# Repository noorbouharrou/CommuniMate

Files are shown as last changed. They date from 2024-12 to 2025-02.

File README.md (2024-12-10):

# CommuniMate

## Getting started

To make it easy for you to get started with GitLab, here's a list of recommended next steps.

Already a pro? Just edit this README.md and make it your own. Want to make it easy? [Use the template at the bottom](#editing-this-readme)!

## Add your files

- [ ] [Create](https://docs.gitlab.com/ee/user/project/repository/web_editor.html#create-a-file) or [upload](https://docs.gitlab.com/ee/user/project/repository/web_editor.html#upload-a-file) files
- [ ] [Add files using the command line](https://docs.gitlab.com/ee/gitlab-basics/add-file.html#add-a-file-using-the-command-line) or push an existing Git repository with the following command:

```
cd existing_repo
git remote add origin https://gitlab.cmi.hro.nl/1048112/communimate.git
git branch -M main
git push -uf origin main
```

## Integrate with your tools

- [ ] [Set up project integrations](https://gitlab.cmi.hro.nl/1048112/communimate/-/settings/integrations)

## Collaborate with your team

- [ ] [Invite team members and collaborators](https://docs.gitlab.com/ee/user/project/members/)
- [ ] [Create a new merge request](https://docs.gitlab.com/ee/user/project/merge_requests/creating_merge_requests.html)
- [ ] [Automatically close issues from merge requests](https://docs.gitlab.com/ee/user/project/issues/managing_issues.html#closing-issues-automatically)
- [ ] [Enable merge request approvals](https://docs.gitlab.com/ee/user/project/merge_requests/approvals/)
- [ ] [Set auto-merge](https://docs.gitlab.com/ee/user/project/merge_requests/merge_when_pipeline_succeeds.html)

## Test and Deploy

Use the built-in continuous integration in GitLab.

- [ ] [Get started with GitLab CI/CD](https://docs.gitlab.com/ee/ci/quick_start/index.html)
- [ ] [Analyze your code for known vulnerabilities with Static Application Security Testing (SAST)](https://docs.gitlab.com/ee/user/application_security/sast/)
- [ ] [Deploy to Kubernetes, Amazon EC2, or Amazon ECS using Auto Deploy](https://docs.gitlab.com/ee/topics/autodevops/requirements.html)
- [ ] [Use pull-based deployments for improved Kubernetes management](https://docs.gitlab.com/ee/user/clusters/agent/)
- [ ] [Set up protected environments](https://docs.gitlab.com/ee/ci/environments/protected_environments.html)

***

# Editing this README

When you're ready to make this README your own, just edit this file and use the handy template below (or feel free to structure it however you want - this is just a starting point!). Thanks to [makeareadme.com](https://www.makeareadme.com/) for this template.

## Suggestions for a good README

Every project is different, so consider which of these sections apply to yours. The sections used in the template are suggestions for most open source projects. Also keep in mind that while a README can be too long and detailed, too long is better than too short. If you think your README is too long, consider utilizing another form of documentation rather than cutting out information.

## Name
Choose a self-explaining name for your project.

## Description
Let people know what your project can do specifically. Provide context and add a link to any reference visitors might be unfamiliar with. A list of Features or a Background subsection can also be added here. If there are alternatives to your project, this is a good place to list differentiating factors.

## Badges
On some READMEs, you may see small images that convey metadata, such as whether or not all the tests are passing for the project. You can use Shields to add some to your README. Many services also have instructions for adding a badge.

## Visuals
Depending on what you are making, it can be a good idea to include screenshots or even a video (you'll frequently see GIFs rather than actual videos). Tools like ttygif can help, but check out Asciinema for a more sophisticated method.

## Installation
Within a particular ecosystem, there may be a common way of installing things, such as using Yarn, NuGet, or Homebrew. However, consider the possibility that whoever is reading your README is a novice and would like more guidance. Listing specific steps helps remove ambiguity and gets people to using your project as quickly as possible. If it only runs in a specific context like a particular programming language version or operating system or has dependencies that have to be installed manually, also add a Requirements subsection.

## Usage
Use examples liberally, and show the expected output if you can. It's helpful to have inline the smallest example of usage that you can demonstrate, while providing links to more sophisticated examples if they are too long to reasonably include in the README.

## Support
Tell people where they can go to for help. It can be any combination of an issue tracker, a chat room, an email address, etc.

## Roadmap
If you have ideas for releases in the future, it is a good idea to list them in the README.

## Contributing
State if you are open to contributions and what your requirements are for accepting them.

For people who want to make changes to your project, it's helpful to have some documentation on how to get started. Perhaps there is a script that they should run or some environment variables that they need to set. Make these steps explicit. These instructions could also be useful to your future self.

You can also document commands to lint the code or run tests. These steps help to ensure high code quality and reduce the likelihood that the changes inadvertently break something. Having instructions for running tests is especially helpful if it requires external setup, such as starting a Selenium server for testing in a browser.

## Authors and acknowledgment
Show your appreciation to those who have contributed to the project.

## License
For open source projects, say how it is licensed.

## Project status
If you have run out of energy or time for your project, put a note at the top of the README saying that development has slowed down or stopped completely. Someone may choose to fork your project or volunteer to step in as a maintainer or owner, allowing your project to keep going. You can also make an explicit request for maintainers.

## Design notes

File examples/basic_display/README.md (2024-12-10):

Put the User_Setup.h in the Documents > Arduino > libraries > TFT_eSPI
Library: https://github.com/Bodmer/TFT_eSPI/tree/master

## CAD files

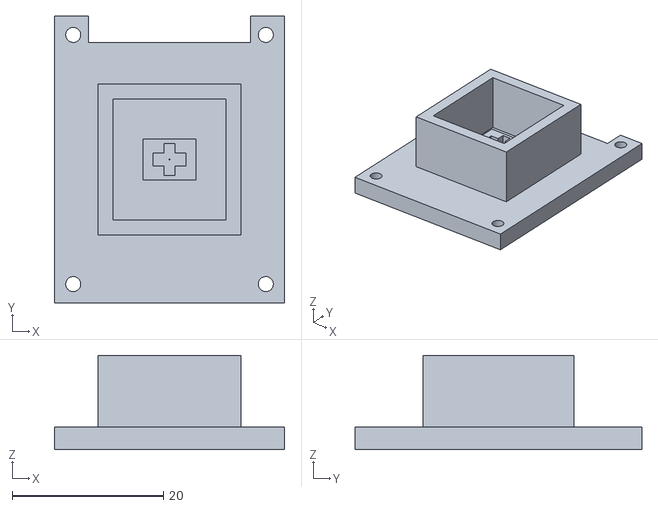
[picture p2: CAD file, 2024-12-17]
ontwerpen/keycap-adapter/key_adapter_V1.stl
30.5 x 38.0 x 12.5

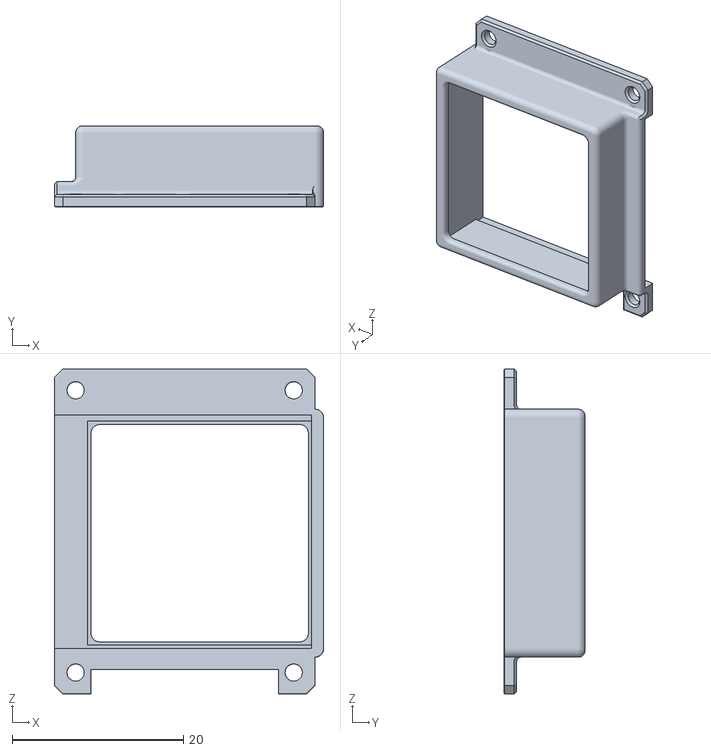
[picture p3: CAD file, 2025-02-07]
ontwerpen/keycap-adapter/STL's/Toets_topshell.STL
31.5 x 9.50 x 38.0

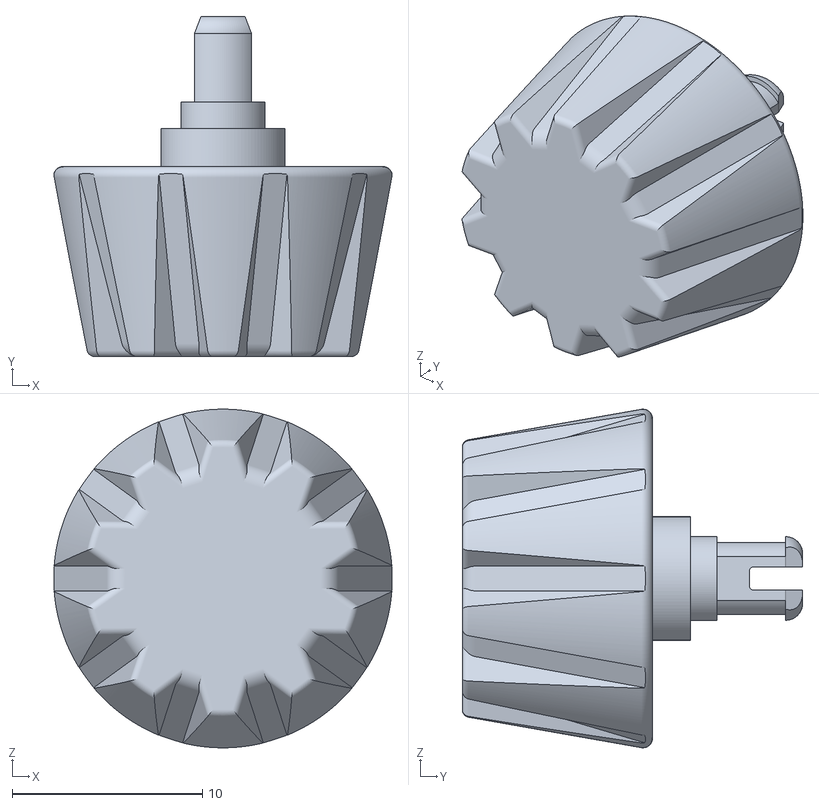
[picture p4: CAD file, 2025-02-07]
ontwerpen/keycap-adapter/STL's/Draaiknop_volume.STL
17.8 x 17.9 x 17.8

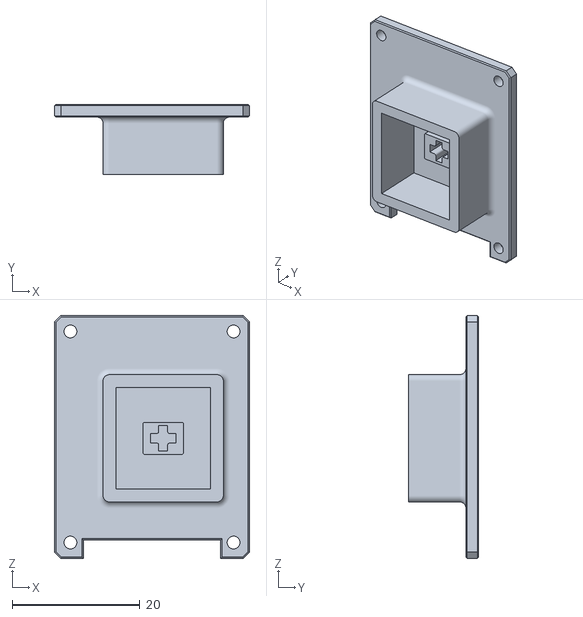
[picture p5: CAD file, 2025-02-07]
ontwerpen/keycap-adapter/STL's/Toets_bottomshell.STL
30.5 x 11.0 x 38.0

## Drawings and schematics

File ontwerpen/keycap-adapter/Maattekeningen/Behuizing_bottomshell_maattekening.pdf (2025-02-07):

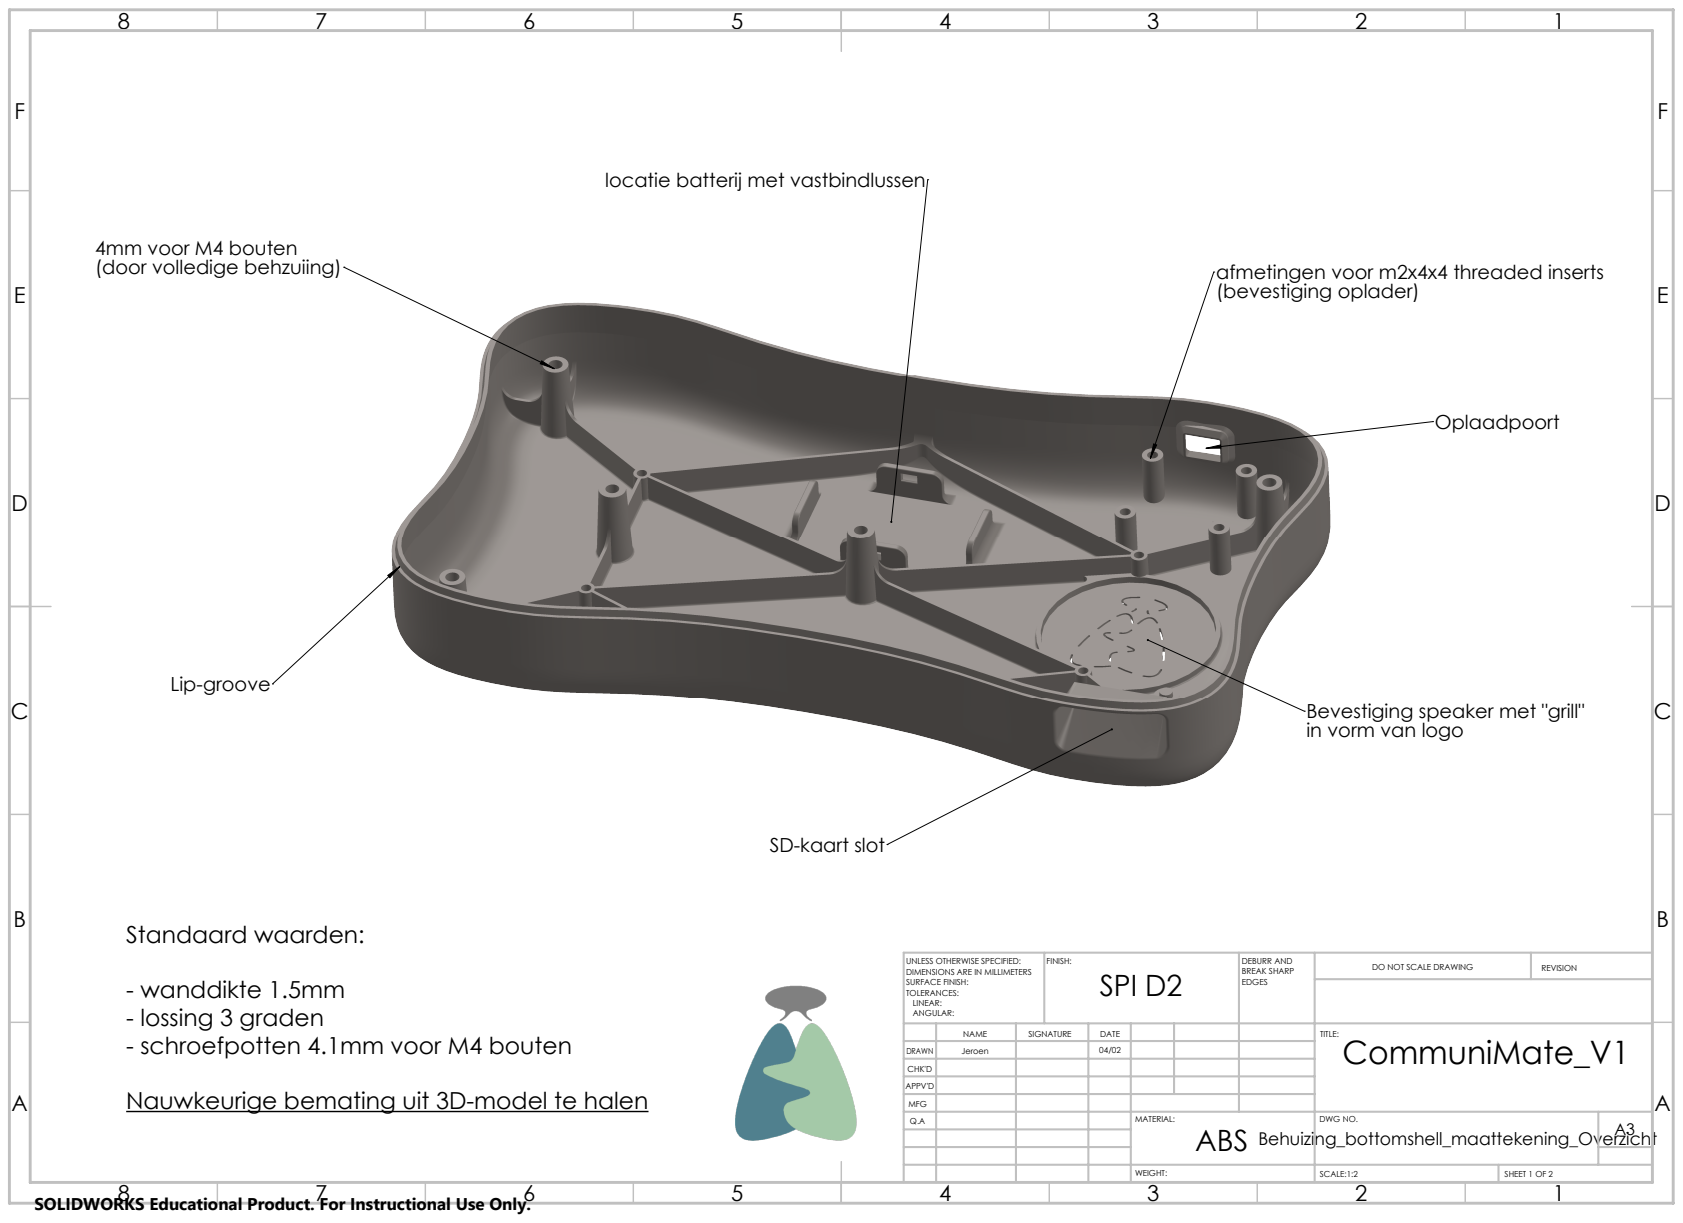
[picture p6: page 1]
4mm voor M4 bouten; (door volledige behzuiing); afmetingen voor m2x4x4 threaded inserts; (bevestiging oplader); Nauwkeurige bemating uit 3D-model te halen; FINISH:; DEBURR AND; BREAK SHARP; DO NOT SCALE DRAWING; REVISION; SCALE:1:2; SHEET 1 OF 2; SPI D2

locatie batterij met vastbindlussen

Bevestiging speaker met "grill"
in vorm van logo

SD-kaart slot

Standaard waarden:
- wanddikte 1.5mm
- lossing 3 graden
- schroefpotten 4.1mm voor M4 bouten

UNLESS OTHERWISE SPECIFIED:
DIMENSIONS ARE IN MILLIMETERS
SURFACE FINISH:
TOLERANCES:
LINEAR:
ANGULAR:

NAME | SIGNATURE | DATE | | | | TITLE: CommuniMate_V1

DRAWN | Jeroen | | 04/02
CHK'D
APPV'D
MFG
Q.A | | | | MATERIAL: ABS Behuizing_bottomshell_maattekening_Overzicht | DWG NO. | A3

SOLIDWORKS Educational Product. For Instructional Use Only.

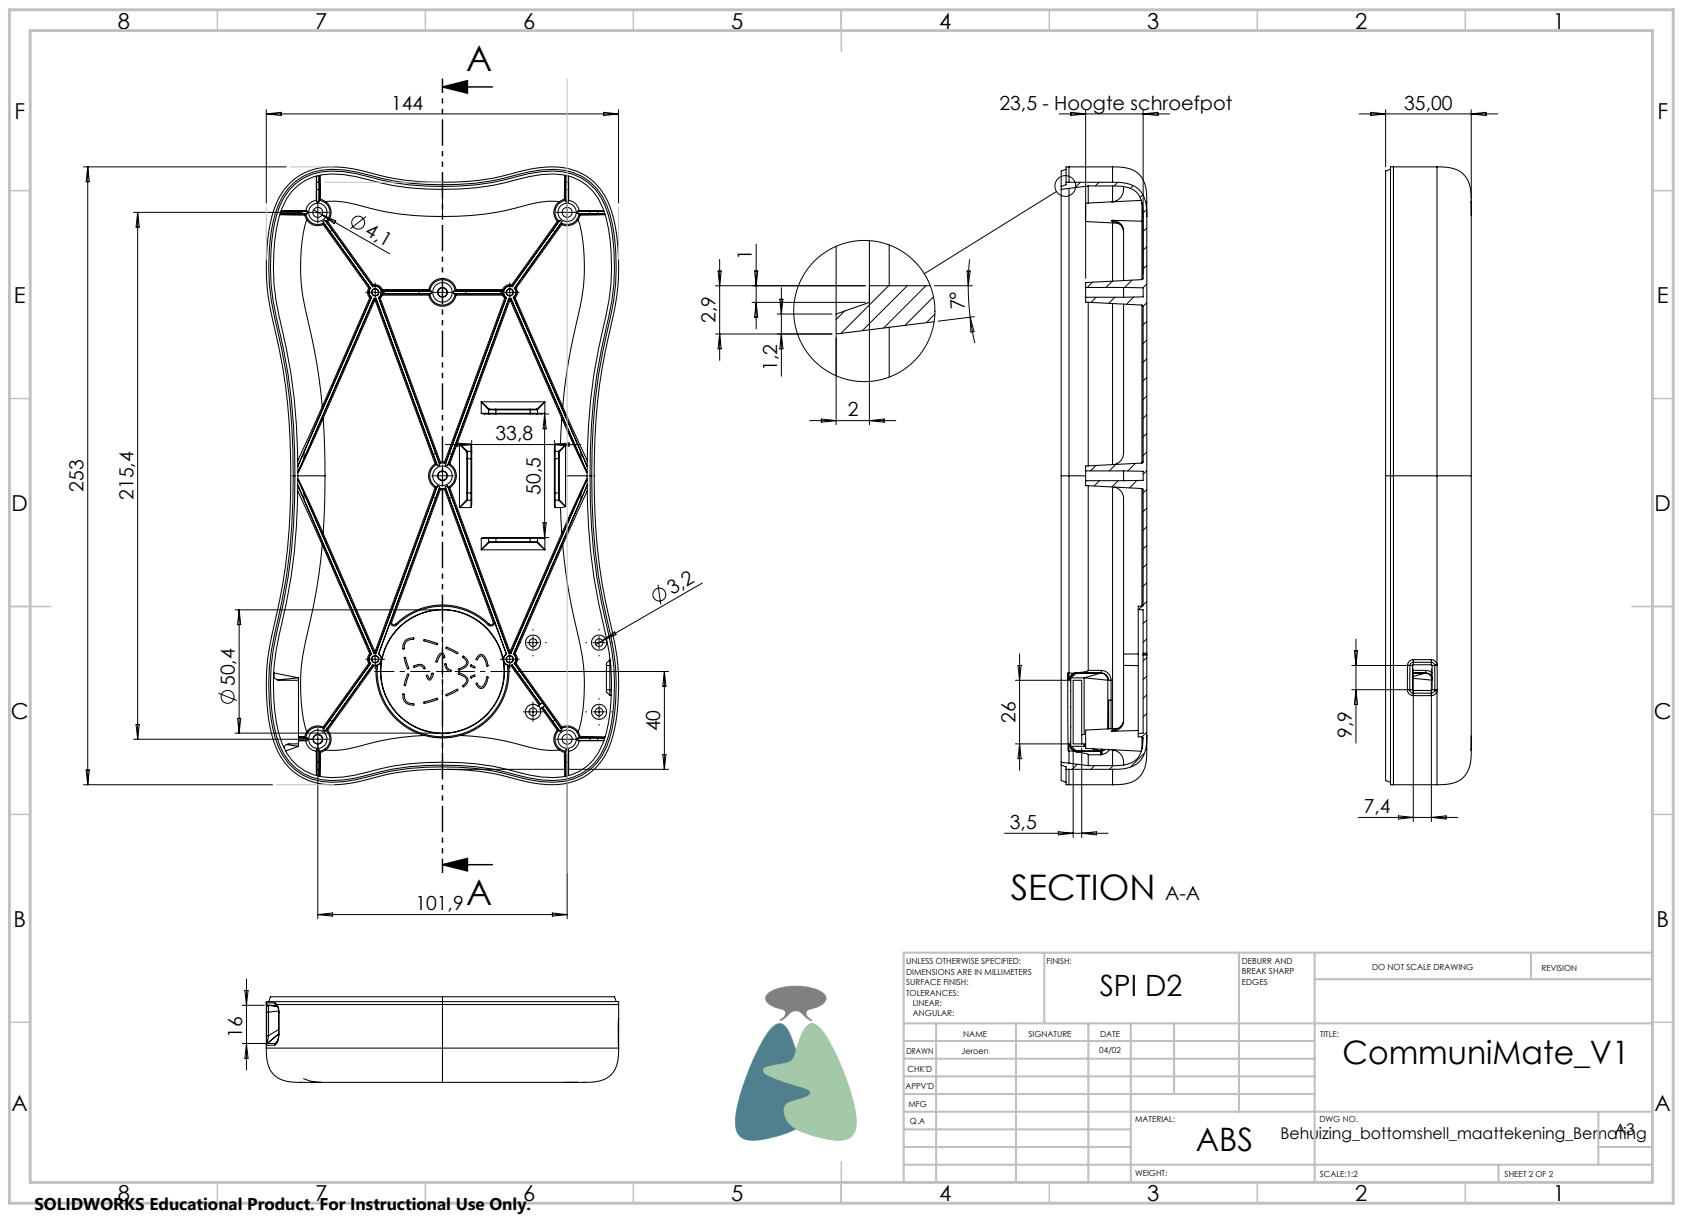
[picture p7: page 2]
23,5 - Hoogte schroefpot; SECTION A-A; FINISH:; DEBURR AND; BREAK SHARP; DO NOT SCALE DRAWING; REVISION; SCALE:1:2; SHEET 2 OF 2; SPI D2

UNLESS OTHERWISE SPECIFIED:
DIMENSIONS ARE IN MILLIMETERS
SURFACE FINISH:
TOLERANCES:
LINEAR:
ANGULAR:

NAME | SIGNATURE | DATE | | | | TITLE: CommuniMate_V1

DRAWN | Jeroen | | 04/02
CHK'D
APPV'D
MFG
Q.A | | | | MATERIAL: ABS Behuizing_bottomshell_maattekening_Bemating | DWG NO. | A3

SOLIDWORKS Educational Product. For Instructional Use Only.

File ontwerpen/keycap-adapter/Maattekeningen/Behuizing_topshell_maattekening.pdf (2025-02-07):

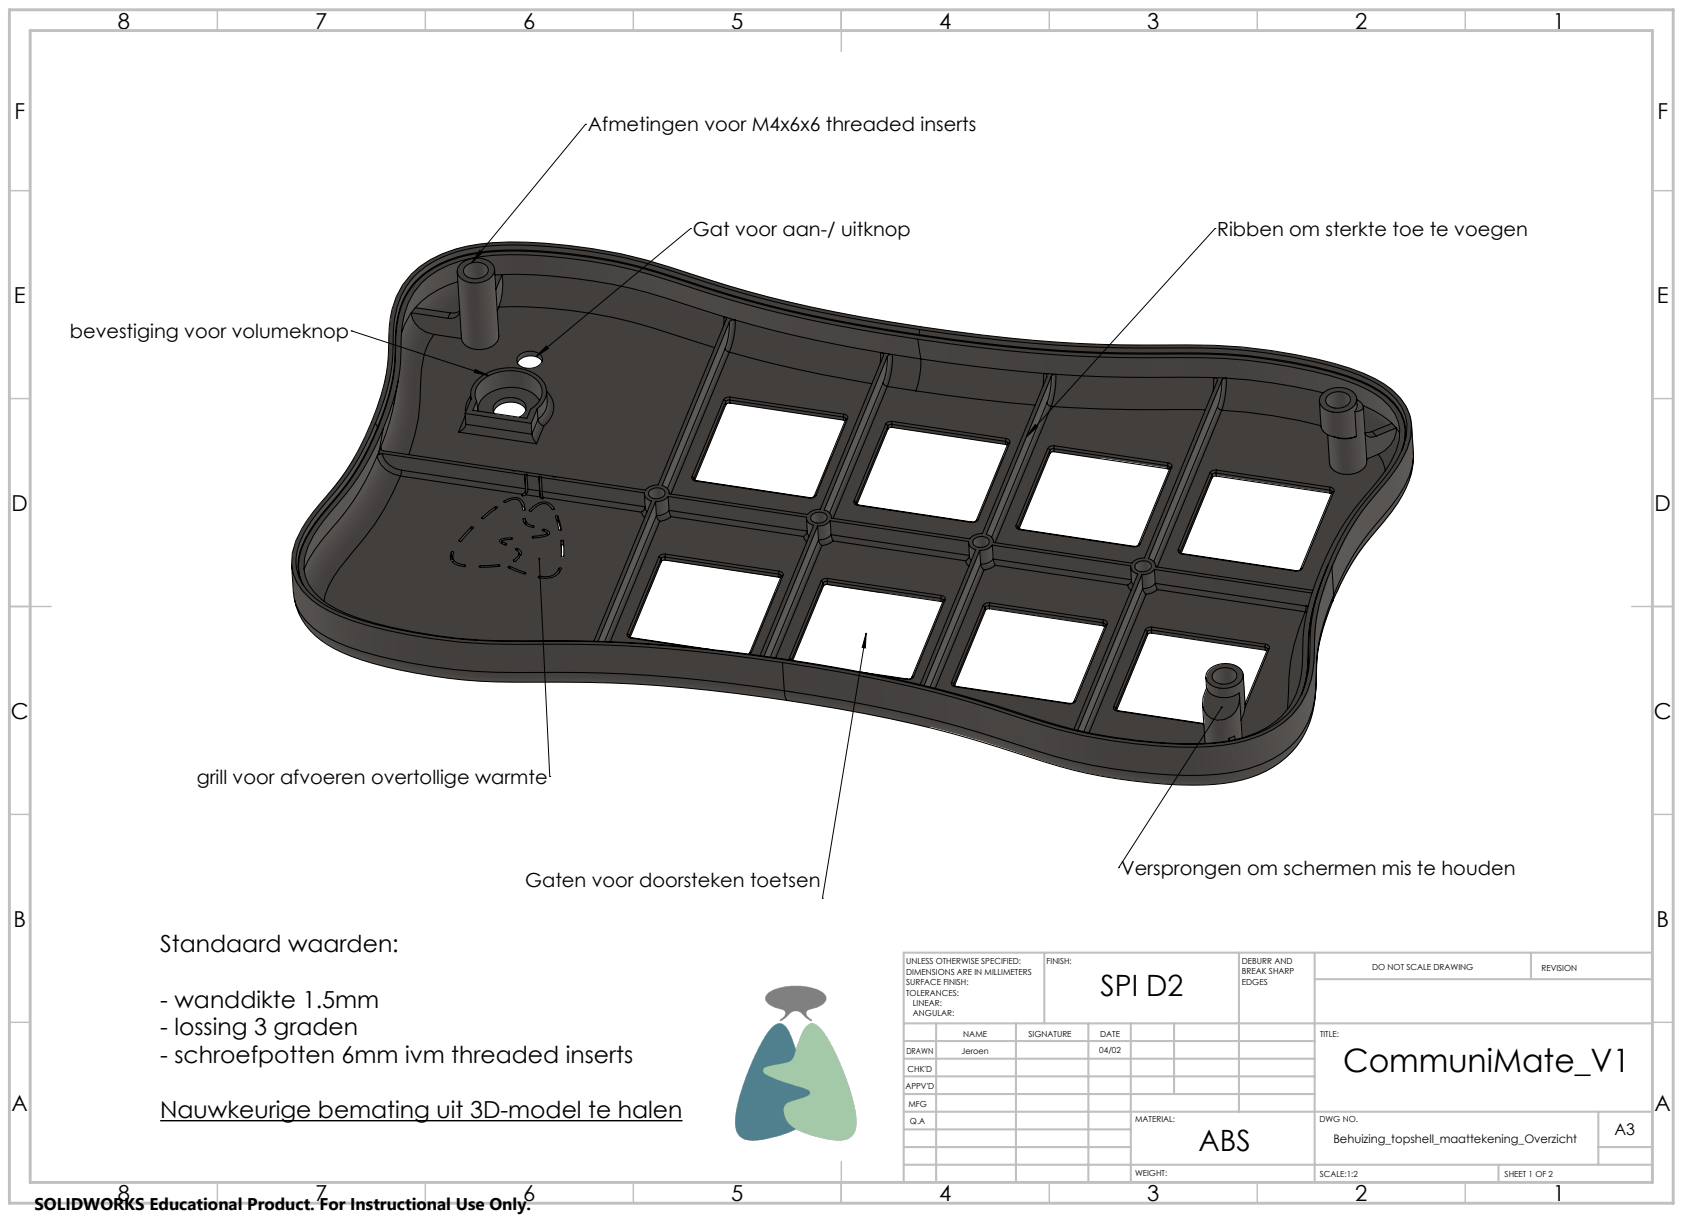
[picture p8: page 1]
Nauwkeurige bemating uit 3D-model te halen; FINISH:; DEBURR AND; BREAK SHARP; DO NOT SCALE DRAWING; REVISION; SCALE:1:2; SHEET 1 OF 2; SPI D2

Afmetingen voor M4x6x6 threaded inserts

Gat voor aan-/ uitknop

Ribben om sterkte toe te voegen

bevestiging voor volumeknop

grill voor afvoeren overtollige warmte

Versprongen om schermen mis te houden

Gaten voor doorsteken toetsen

Standaard waarden:
- wanddikte 1.5mm
- lossing 3 graden
- schroefpotten 6mm ivm threaded inserts

UNLESS OTHERWISE SPECIFIED:
DIMENSIONS ARE IN MILLIMETERS
SURFACE FINISH:
TOLERANCES:
LINEAR:
ANGULAR:

NAME | SIGNATURE | DATE | | | | TITLE: CommuniMate_V1

DRAWN | Jeroen | | 04/02
CHK'D
APPV'D
MFG
Q.A | | | | MATERIAL: ABS | DWG NO. Behuizing_topshell_maattekening_Overzicht | A3

SOLIDWORKS Educational Product. For Instructional Use Only.

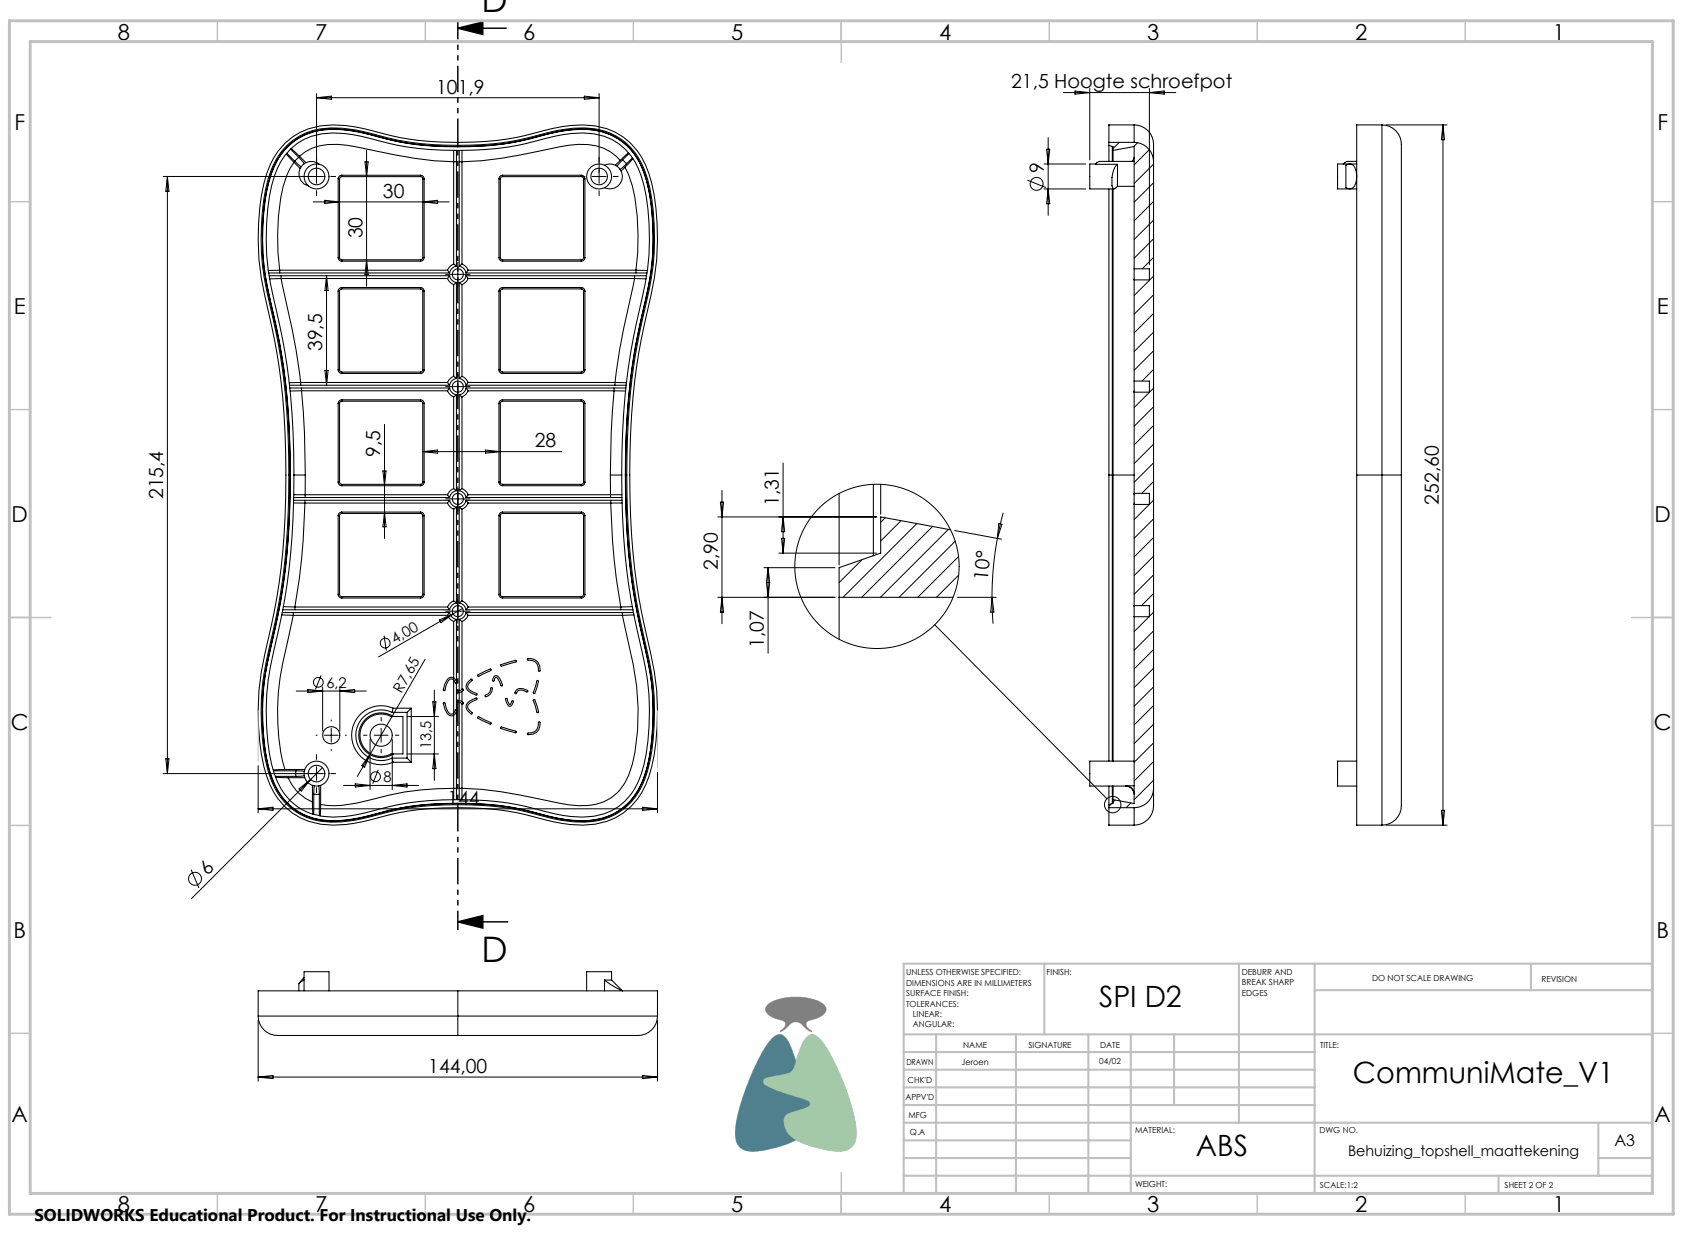
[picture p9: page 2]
21,5 Hoogte schroefpot 9; FINISH:; DEBURR AND; BREAK SHARP; DO NOT SCALE DRAWING; REVISION; SCALE:1:2; SHEET 2 OF 2; SPI D2

UNLESS OTHERWISE SPECIFIED:
DIMENSIONS ARE IN MILLIMETERS
SURFACE FINISH:
TOLERANCES:
LINEAR:
ANGULAR:

NAME | SIGNATURE | DATE | | | | TITLE: CommuniMate_V1

DRAWN | Jeroen | | 04/02
CHK'D
APPV'D
MFG
Q.A | | | | MATERIAL: ABS | DWG NO. Behuizing_topshell_maattekening | A3

SOLIDWORKS Educational Product. For Instructional Use Only.

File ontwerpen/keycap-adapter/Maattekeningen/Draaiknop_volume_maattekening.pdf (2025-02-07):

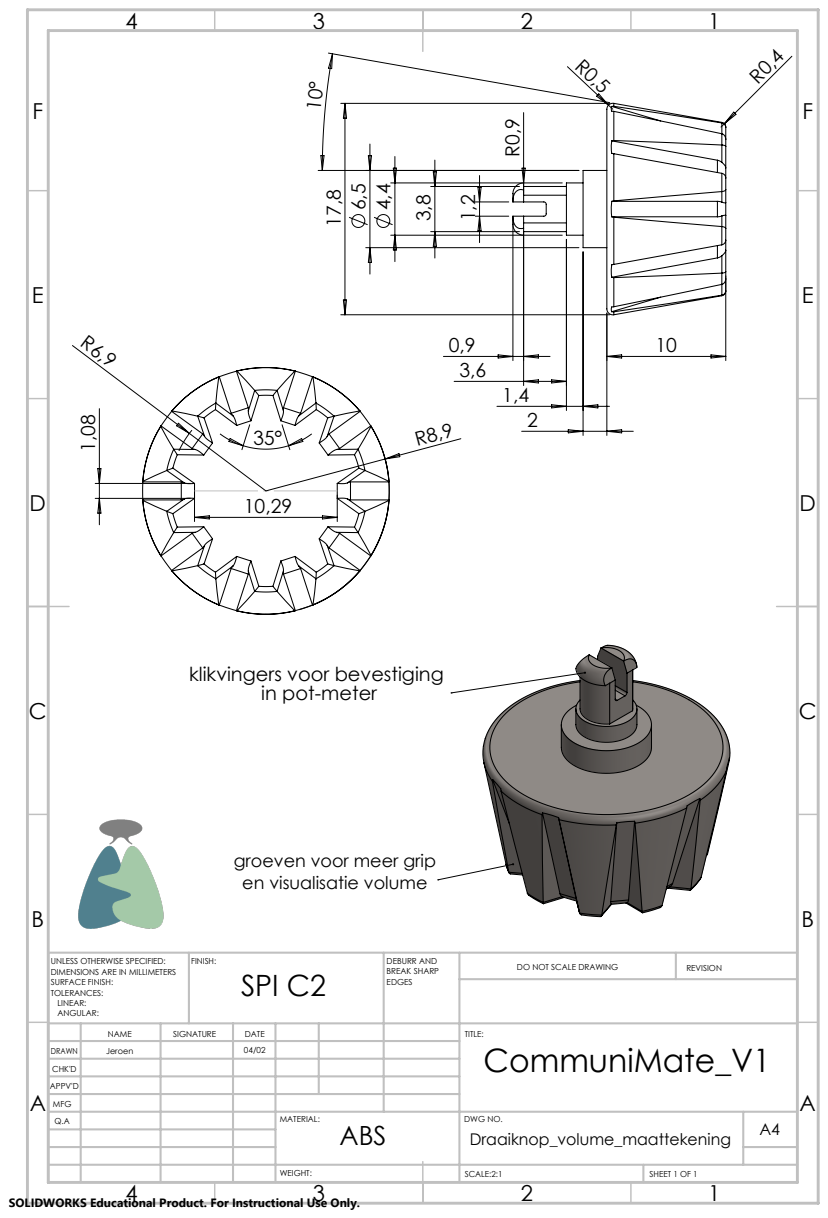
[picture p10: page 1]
en visualisatie volume 4,4; FINISH:; DEBURR AND; BREAK SHARP; DO NOT SCALE DRAWING; REVISION; SCALE:2:1; SHEET 1 OF 1; SPI C2

klikvingers voor bevestiging
in pot-meter

groeven voor meer grip

UNLESS OTHERWISE SPECIFIED:
DIMENSIONS ARE IN MILLIMETERS
SURFACE FINISH:
TOLERANCES:
LINEAR:
ANGULAR:

NAME | SIGNATURE | DATE | | | | TITLE: CommuniMate_V1

DRAWN | Jeroen | | 04/02
CHK'D
APPV'D
MFG
Q.A | | | | MATERIAL: | DWG NO. Draaiknop_volume_maattekening | A4 ABS

SOLIDWORKS Educational Product. For Instructional Use Only.

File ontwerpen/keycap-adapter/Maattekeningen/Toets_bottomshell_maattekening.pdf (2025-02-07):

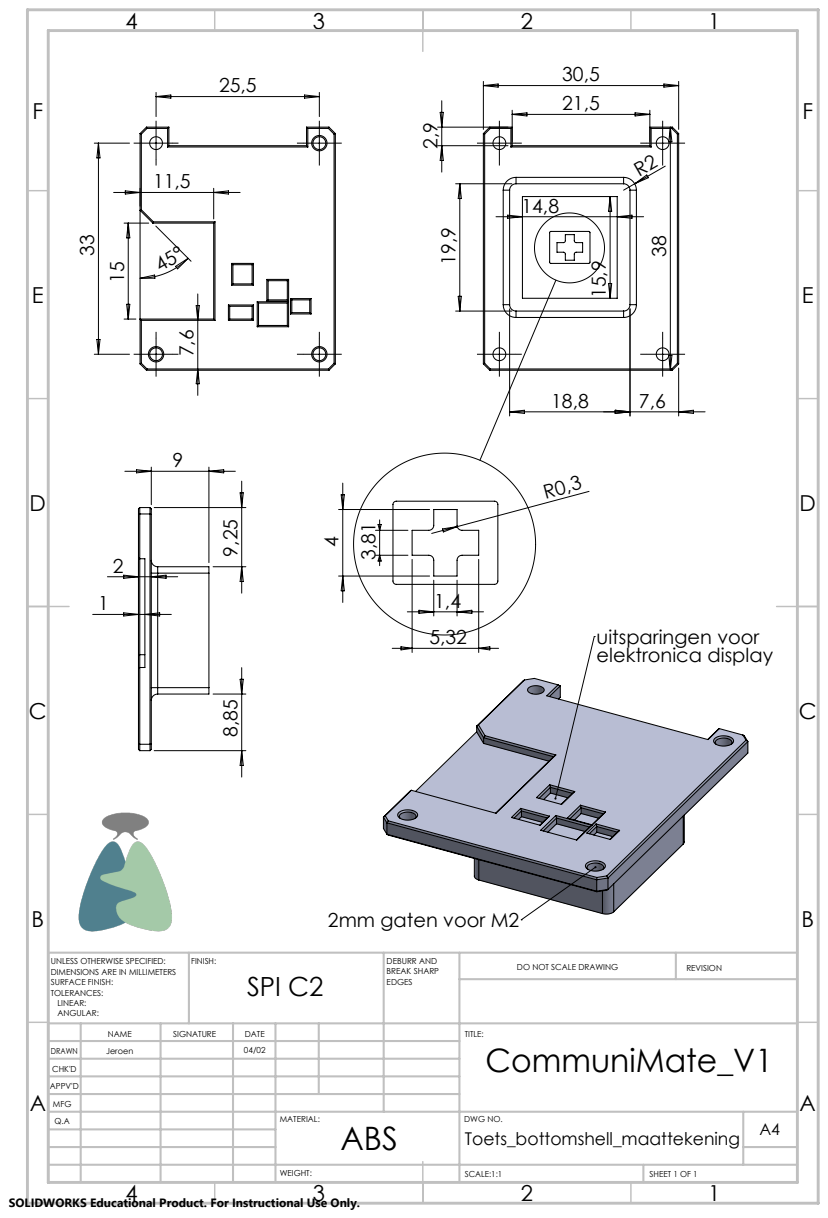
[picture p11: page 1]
uitsparingen voor elektronica display; 2mm gaten voor M2; FINISH:; DEBURR AND; BREAK SHARP; DO NOT SCALE DRAWING; REVISION; SCALE:1:1; SHEET 1 OF 1; SPI C2

UNLESS OTHERWISE SPECIFIED:
DIMENSIONS ARE IN MILLIMETERS
SURFACE FINISH:
TOLERANCES:
LINEAR:
ANGULAR:

NAME | SIGNATURE | DATE | | | | TITLE: CommuniMate_V1

DRAWN | Jeroen | | 04/02
CHK'D
APPV'D
MFG
Q.A | | | | MATERIAL: | DWG NO. Toets_bottomshell_maattekening | A4 ABS

SOLIDWORKS Educational Product. For Instructional Use Only.

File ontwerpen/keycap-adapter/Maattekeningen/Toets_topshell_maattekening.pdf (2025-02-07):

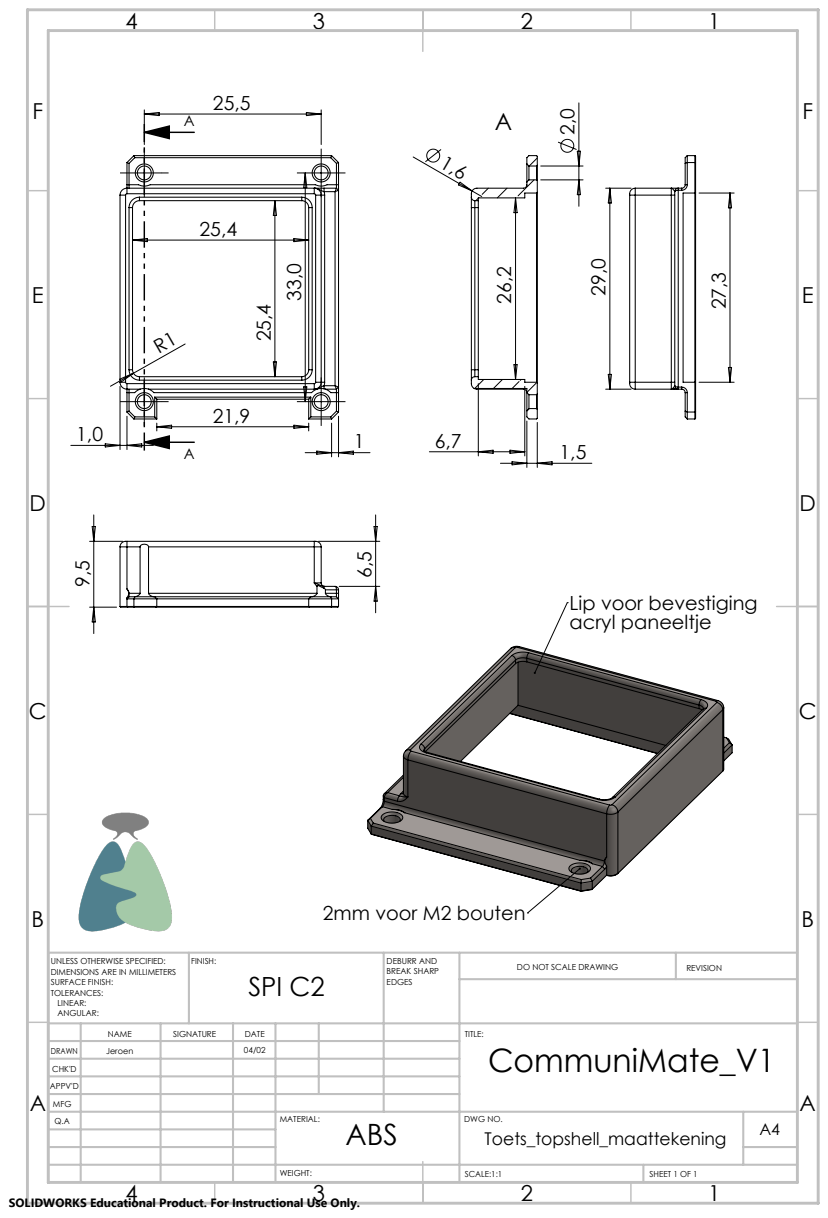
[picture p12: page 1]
2mm voor M2 bouten; FINISH:; DEBURR AND; BREAK SHARP; DO NOT SCALE DRAWING; REVISION; SCALE:1:1; SHEET 1 OF 1; SPI C2

Lip voor bevestiging
acryl paneeltje

UNLESS OTHERWISE SPECIFIED:
DIMENSIONS ARE IN MILLIMETERS
SURFACE FINISH:
TOLERANCES:
LINEAR:
ANGULAR:

NAME | SIGNATURE | DATE | | | | TITLE: CommuniMate_V1

DRAWN | Jeroen | | 04/02
CHK'D
APPV'D
MFG
Q.A | | | | MATERIAL: ABS | DWG NO. Toets_topshell_maattekening | A4

SOLIDWORKS Educational Product. For Instructional Use Only.

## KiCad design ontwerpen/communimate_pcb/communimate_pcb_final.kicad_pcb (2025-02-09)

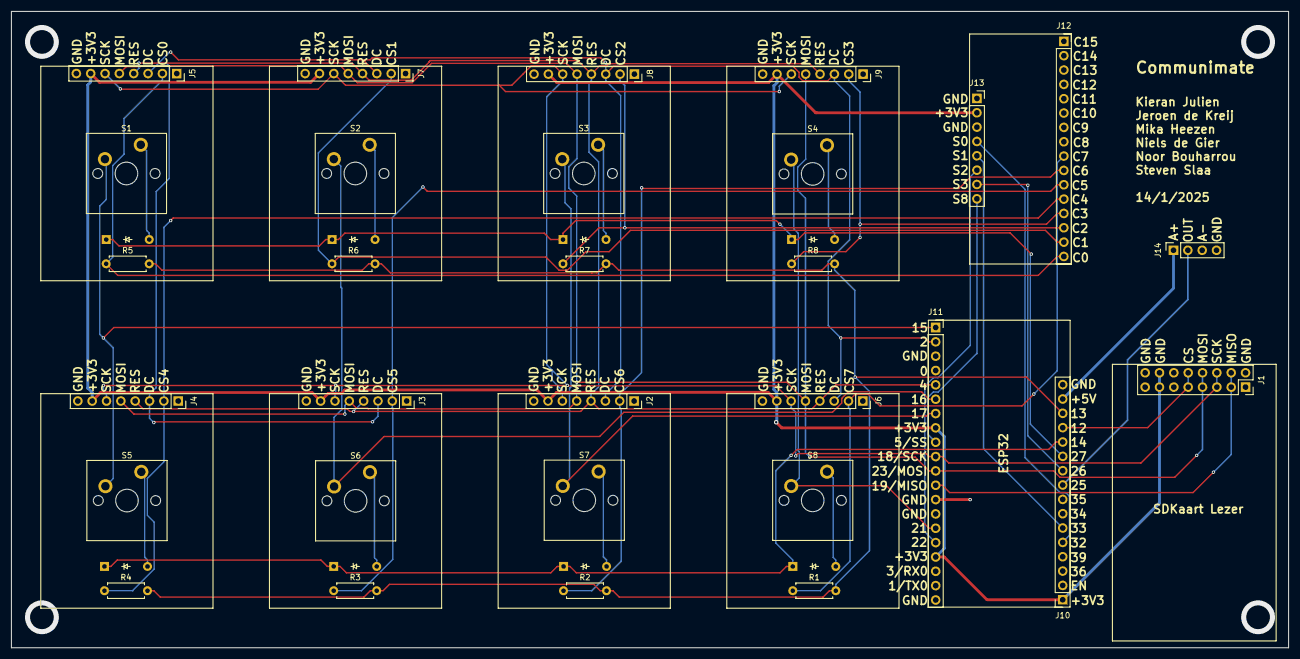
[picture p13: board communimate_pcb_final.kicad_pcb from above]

Board: 2 copper layers, 226.2 x 112.7 mm, 38 parts (0 on the bottom side), 38 nets.

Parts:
D1, D2, D3, D4, D5, D6, D7, D8: Diode; Diode_DO-35
J1: Conn_02x08_Counter_Clockwise; PinSocket_2x08_P2.54mm_Vertical
J2, J3, J4, J5, J6, J7, J8, J9, J13: Conn_01x08; PinSocket_1x08_P2.54mm_Vertical
J10, J12: Conn_01x16; PinSocket_1x16_P2.54mm_Vertical
J11: Conn_01x20; PinSocket_1x20_P2.54mm_Vertical
J14: Conn_01x04; PinSocket_1x04_P2.54mm_Vertical
R1, R2, R3, R4, R5, R6, R7, R8: Resistor; R_Axial_DIN0207_L6.3mm_D2.5mm_P7.62mm_Horizontal
S1, S2, S3, S4, S5, S6, S7, S8: Keyswitch; MX_PCB_1.00u

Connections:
+3V3: J1.13, J1.14, J2.7, J3.7, J4.7, J5.7, J6.7, J7.7, J8.7, J9.7, J10.1, J11.8, J11.17, J13.2
+5V: J10.15, J14.1
AUDIO: J10.9, J14.2
Channel 0: J5.2, J12.16, R5.1
Channel 1: J7.2, J12.15, R6.1
Channel 2: J8.2, J12.14, R7.1
Channel 3: J9.2, J12.13, R8.1
Channel 4: J4.2, J12.12, R4.1
Channel 5: J3.2, J12.11, R3.1
Channel 6: J2.2, J12.10, R2.1
Channel 7: J6.2, J12.9, R1.1
Column 0: J11.1, S1.1, S5.1
Column 1: J11.6, S2.1, S6.1
Column 2: J11.7, S3.1, S7.1
Column 3: J11.15, S4.1, S8.1
DC: J2.3, J3.3, J4.3, J5.3, J6.3, J7.3, J8.3, J9.3, J11.2
GND: J1.1, J1.2, J1.15, J1.16, J2.8, J3.8, J4.8, J5.8, J6.8, J7.8, J8.8, J9.8, J10.16, J11.3, J11.13, J11.14, J11.20, J13.1, J13.3, J14.3, J14.4
MISO: J1.3, J1.4, J11.12
MOSI: J1.7, J1.8, J2.5, J3.5, J4.5, J5.5, J6.5, J7.5, J8.5, J9.5, J11.11
unnamed: D1.2 (A), S1.2
unnamed: D2.2 (A), S2.2
unnamed: D3.2 (A), S3.2
unnamed: D4.2 (A), S4.2
unnamed: D5.2 (A), S5.2
unnamed: D6.2 (A), S6.2
unnamed: D7.2 (A), S7.2
unnamed: D8.2 (A), S8.2
PULLUP: J10.14, R1.2, R2.2, R3.2, R4.2, R5.2, R6.2, R7.2, R8.2
RES: J2.4, J3.4, J4.4, J5.4, J6.4, J7.4, J8.4, J9.4, J11.5
Row 0: D1.1 (K), D2.1 (K), D3.1 (K), D4.1 (K), J10.11
Row 1: D5.1 (K), D6.1 (K), D7.1 (K), D8.1 (K), J10.12
S0: J10.5, J13.4
S1: J10.6, J13.5
S2: J11.16, J13.6
S3: J10.10, J13.7
SCK: J1.5, J1.6, J2.6, J3.6, J4.6, J5.6, J6.6, J7.6, J8.6, J9.6, J11.10
SCREENCS: J11.9, J13.8
SDCS: J1.9, J1.10, J10.13

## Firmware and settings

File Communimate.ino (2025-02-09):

/*
===========================================================
Project Name: Communimate
Authors:  
- Niels de Gier  
- Kieran Julien
- Mika Heezen  
- Jeroen de Kreij  
- Noor Bouharrou  
Date: 8/2/2025
Description:
This project uses an ESP32 to display images on TFT-screens with help form a multiplexer.
It also reads button presses and plays an corresponding audio file.  
===========================================================
*/

//import library's
#include <SPI.h>
#include <FS.h>
#include <SD.h>
#include <PNGdec.h>
#include <TFT_eSPI.h>
#include "driver/dac.h"

//define audio 
#define DAC_CH1 DAC_CHANNEL_1
#define SAMPLE_RATE 8000
#define sdCardOutPin 12
TFT_eSPI tft = TFT_eSPI();

File wavFile;
PNG png;

//multiplexer control pins connected to ESP32
const int S0 = 32;
const int S1 = 33;
const int S2 = 22;
const int S3 = 26;
const int muxControlPins[] = { S0, S1, S2, S3 };
const int pullUpLine = 13;
#define MAX_IMAGE_WIDTH 240
int16_t xpos = 0, ypos = 0;
bool playingAudio = false; 


// Keypad matrix
const int rows[] = {27, 14};
const int cols[] = {15, 16, 17, 21};
const int numRows = sizeof(rows) / sizeof(rows[0]);
const int numCols = sizeof(cols) / sizeof(cols[0]);

bool keyStates[numRows][numCols] = {false};

const char keymap[numRows][numCols] = {
  {'1', '2', '3', '4'}, // Row 0 keys
  {'5', '6', '7', '8'}  // Row 1 keys
};

//Selector function for multiplexer
//takes int channel: multiplexer channel that should be active
void selectMuxChannel(int channel) {
  for (int i = 0; i < 4; i++) {
    digitalWrite(muxControlPins[i], (channel >> i) & 1);
  }
}

//custom fileread function for PNG-decoder
int32_t fileReader(PNGFILE *pFile, uint8_t *pBuf, int32_t iLen) {
  File *f = reinterpret_cast<File *>(pFile->fHandle);
  return f->read(pBuf, iLen);
}

//custom fileseek function to search for a specific location in a file
int32_t fileSeek(PNGFILE *pFile, int32_t iPosition) {
  File *f = reinterpret_cast<File *>(pFile->fHandle);
  f->seek(iPosition);
  return iPosition;
}

//custom open file fuctions to open a file from the SD card
void *fileOpen(const char *filename, int32_t *size) {
  File *f = new File(SD.open(filename));
  if (f && *f) {
    *size = f->size();
    return reinterpret_cast<void *>(f);
  }
  delete f;
  return nullptr;
}

//custom file close function to close a file
void fileClose(void *handle) {
  File *f = reinterpret_cast<File *>(handle);
  if (f) f->close();
  delete f;
}

//function to render an image to a screen
void pngDraw(PNGDRAW *pDraw) {
  uint16_t lineBuffer[MAX_IMAGE_WIDTH];
  png.getLineAsRGB565(pDraw, lineBuffer, PNG_RGB565_LITTLE_ENDIAN, 0xFFFFFFFF);
  tft.pushImage(xpos, ypos + pDraw->y, pDraw->iWidth, 1, lineBuffer);
  
}

//function to load and draw an png image form an sd-card
//takes char *filename: the file name of the png image
//int channel: the multiplexer chanel that needs to be active
void drawSdPNG(const char *filename, int channel) {

  bool swapBytes = tft.getSwapBytes();
  tft.setSwapBytes(true);

  File pngFile = SD.open(filename, FILE_READ);

  if (!pngFile) {
    Serial.print("ERROR: File \"");
    Serial.print(filename);
    Serial.println("\" not found!");
    return;
    }
}

void setup() {
  Serial.begin(115200);
  dac_output_enable(DAC_CH1);
  pinMode(sdCardOutPin, OUTPUT);
  digitalWrite(sdCardOutPin, HIGH);
  pinMode(pullUpLine, OUTPUT);
  //set pullup line low, so all screens are selected
  digitalWrite(pullUpLine, LOW);

  //setup multiplexer control pins
  for (int i = 0; i < 4; i++) {
    pinMode(muxControlPins[i], OUTPUT);
    digitalWrite(muxControlPins[i], LOW);
  }

  tft.begin();
  tft.setRotation(90);
  tft.fillScreen(TFT_BLUE);

  //set pullup line back to high so that non of the screens are selected
  digitalWrite(pullUpLine, HIGH);

  //start and test SD card module
  if (!SD.begin(12, tft.getSPIinstance())) {
    Serial.println("Card Mount Failed");
    return;
  }
  uint8_t cardType = SD.cardType();

  if (cardType == CARD_NONE) {
    Serial.println("No SD card attached");
    return;
  }

  int x = (tft.width() - 240) / 2 - 1;
  int y = (tft.height() - 240) / 2 - 1;

  //draw all 8 starting images on the respective screen
  for (int i = 0; i < 8; i++){
    std::string filename = "/image" + std::to_string(i) + ".png";
    drawSdPNG(filename.c_str(), 15-i);
  }

  //setup keypad
  for (int i = 0; i < numRows; i++) {
    pinMode(rows[i], OUTPUT);
    digitalWrite(rows[i], HIGH); // Default HIGH
  }
 
  for (int j = 0; j < numCols; j++) {
    pinMode(cols[j], INPUT_PULLUP); // Columns as inputs
  }
  
  for (int i = 0; i < numRows; i++) {
    digitalWrite(rows[i], LOW);
  }
}

void loop() {
  //check if audio should be playing
  if(playingAudio){
    //if auio is at its end return to not be playing audio
    if (!wavFile || !wavFile.available()) {
      playingAudio = false; 
    }
    //play audio
    unsigned char sample = wavFile.read();
    dac_output_voltage(DAC_CH1, sample);
    delayMicroseconds(1000000 / SAMPLE_RATE);
    return;
  }
  //check if button is pressed and play corresponding audio
   for (int i = 0; i < numRows; i++) {
    digitalWrite(rows[i], LOW);
      for (int j = 0; j < numCols; j++) {
      if (digitalRead(cols[j]) == HIGH) {
        int key = keymap[i][j]; 
        String audioName = "/" + String(key) + ".wav";
        wavFile = SD.open(audioName);
        wavFile.seek(44);
        playingAudio = true; 
        if (!wavFile) {
          Serial.println("Failed to open WAV file");
          return;
        }
      }
    }
  }
}

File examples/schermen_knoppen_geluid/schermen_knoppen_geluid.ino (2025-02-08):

#include <TFT_eSPI.h>  // Include the graphics and font library for ST7735 driver chip
#include <SPI.h>        // Include the SPI library to communicate with the display
#include <PNGdec.h>    // PNG decoding library
#include "driver/dac.h"

// Function to get the next sample from the WAV file data

//images
#include "image1.h"
#include "image2.h"
#include "image3.h"
#include "image4.h"
#include "image5.h"
#include "image6.h"
#include "image7.h"
#include "image8.h"

//audio
#include "1.h"
#include "2.h"
#include "3.h"
#include "4.h"
#include "5.h"
#include "6.h"
#include "7.h"
#include "8.h"

#define DAC_CH1 DAC_CHANNEL_1 // DAC_CHANNEL_1 is GPIO25
#define SAMPLE_RATE 8000 // Sample rate of the WAV file (16kHz)
#define MAX_IMAGE_WIDTH 240 // Adjust based on the image dimensions

TFT_eSPI tft = TFT_eSPI();  // Create an instance of the TFT_eSPI class to handle the TFT display
                            // Pins for the display are defined in User_Setup.h (not shown here)
PNG png;

const int rows[] = {27, 14};          // Row pins
const int cols[] = {15, 16, 17, 21};  // Column pins
const int numRows = sizeof(rows) / sizeof(rows[0]);
const int numCols = sizeof(cols) / sizeof(cols[0]);
bool keyStates[numRows][numCols] = {false};

const char keymap[numRows][numCols] = {
  {'1', '2', '3', '4'},
  {'5', '6', '7', '8'}
};

// HC4067 control pins connected to ESP32
const int S0 = 32;  // Channel selection pin S0 (can be any available GPIO on ESP32)
const int S1 = 33;  // Channel selection pin S1
const int S2 = 22;  // Channel selection pin S2
const int S3 = 26;  // Channel selection pin S3
const int muxControlPins[] = {S0, S1, S2, S3};  // Array storing the control pins (S0-S3)

// The multiplexer signal line (connected to TFT displays' CS pins)
const int pullUpLine = 13;     // Pin for controlling pull-up resistor (used to select the displays)
int16_t xpos = 0, ypos = 0;  // Position of the image on the screen

// Function to select the correct multiplexer channel based on the input channel number
void selectMuxChannel(int channel) {
  for (int i = 0; i < 4; i++) {
    // Set S0-S3 pins based on the channel number using bitwise operations
    // (channel >> i) shifts the bits, and & 1 isolates the bit at position i
    digitalWrite(muxControlPins[i], (channel >> i) & 1);
  }
}

const unsigned char* audioFiles[] = {rawData1, rawData2, rawData3, rawData4, rawData5, rawData6, rawData7};
const size_t audioSizes[] = {sizeof(rawData1), sizeof(rawData2), sizeof(rawData3), sizeof(rawData4), sizeof(rawData5), sizeof(rawData6), sizeof(rawData7)};

void playAudio(const unsigned char* audioData, size_t dataSize) {
    for (size_t i = 44; i < dataSize; i++) { // Skip first 44 bytes (WAV header)
        dac_output_voltage(DAC_CH1, audioData[i]);
        delayMicroseconds(1000000 / SAMPLE_RATE);
    }
}

void pngDraw(PNGDRAW *pDraw) {
  uint16_t lineBuffer[MAX_IMAGE_WIDTH];
  png.getLineAsRGB565(pDraw, lineBuffer, PNG_RGB565_BIG_ENDIAN, 0xFFFFFFFF);
  tft.pushImage(xpos, ypos + pDraw->y, pDraw->iWidth, 1, lineBuffer);
}

void setup(void) {
  Serial.begin(115200);

  dac_output_enable(DAC_CH1);

  // Set multiplexer control pins as OUTPUT
  for (int i = 0; i < 4; i++) {
    pinMode(muxControlPins[i], OUTPUT);  // Set each control pin (S0-S3) as an output
    digitalWrite(muxControlPins[i], LOW);  // Set all control pins to LOW to select channel 0 initially
  }

  for (int i = 0; i < numRows; i++) {
    pinMode(rows[i], OUTPUT);
    digitalWrite(rows[i], HIGH); // Default HIGH
  }

    // Set up column pins as INPUT with pull-ups (if required)
  for (int j = 0; j < numCols; j++) {
    pinMode(cols[j], INPUT_PULLUP); // Columns as inputs
  }

  pinMode(pullUpLine, OUTPUT);           // Set pull-up line as OUTPUT
  digitalWrite(pullUpLine, LOW);         // Initially set pull-up line to LOW, selecting all displays

  // Configure the TFT display
  tft.init();                           // Initialize the TFT display
  tft.setRotation(3);                   // Set the rotation of the display (0 degrees)
  tft.setTextSize(3);                   // Set the text size on the display
  tft.fillScreen(TFT_BLACK);

  digitalWrite(pullUpLine, HIGH);       // Set the pull-up line to HIGH, ensuring all displays are deselected
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
